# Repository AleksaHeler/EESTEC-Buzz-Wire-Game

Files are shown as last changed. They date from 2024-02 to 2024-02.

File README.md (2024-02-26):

# EESTEC-Buzz-Wire-Game

Buzz wire game HW for interactive booths made for EESTEC LC Novi Sad. Made in KiCAD and order from PCB manufaturer from China.

## Example

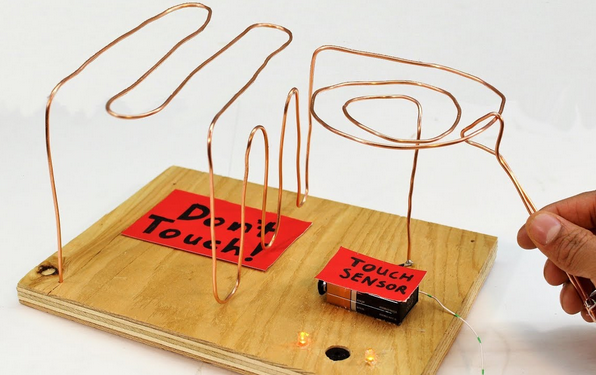
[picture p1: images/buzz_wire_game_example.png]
Buzz wire game example


## Idea

Idea is to make a simple custom HW board for visitors to play with and learn some basic electronics examples.

Using 555 timer chip create an oscillator which beeps a piezo buzzer when wires touch.

## Execution

TODO: add images:
 - schematic
 - PCB (KiCAD view, photos of actual PCBs)
 - board, mounting of all components

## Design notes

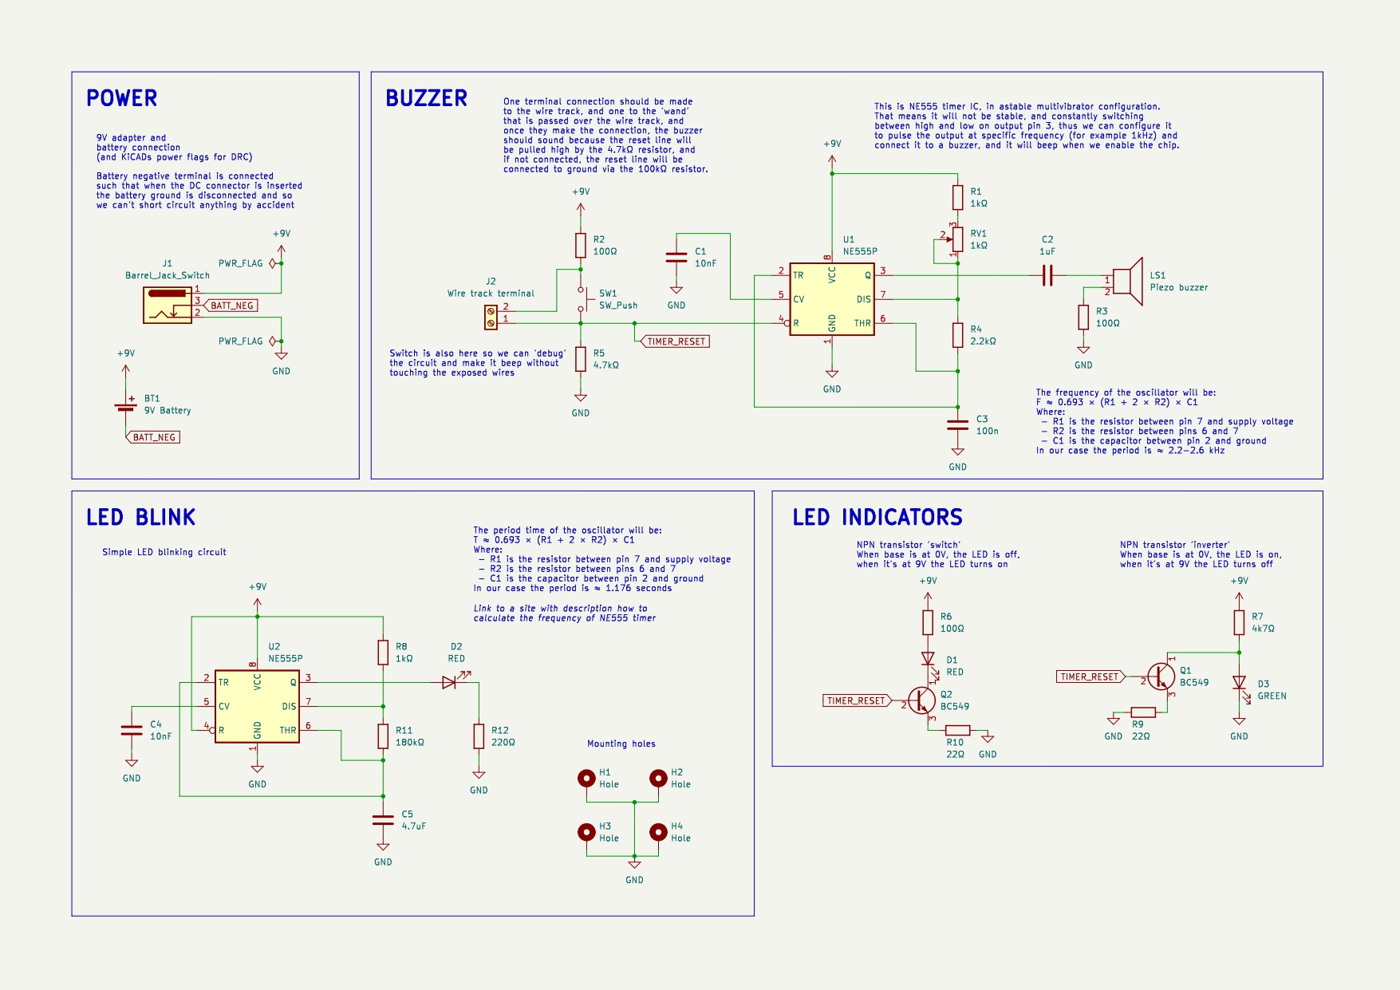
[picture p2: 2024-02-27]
images/Schematic.jpg

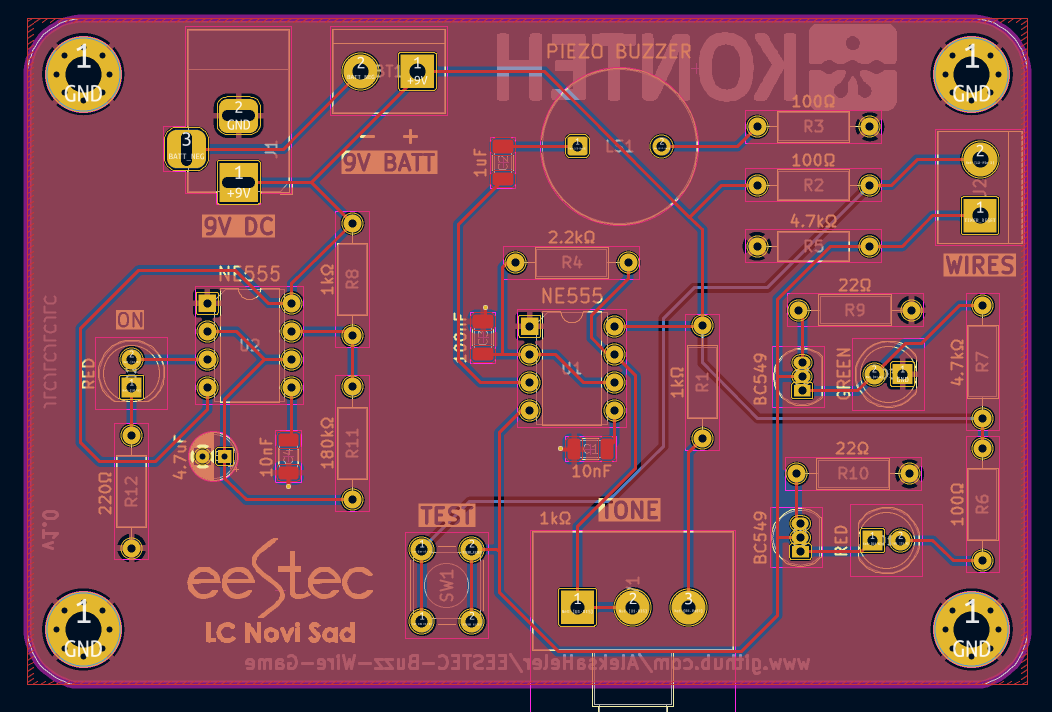
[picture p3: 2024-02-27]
images/PCB_KiCAD.png

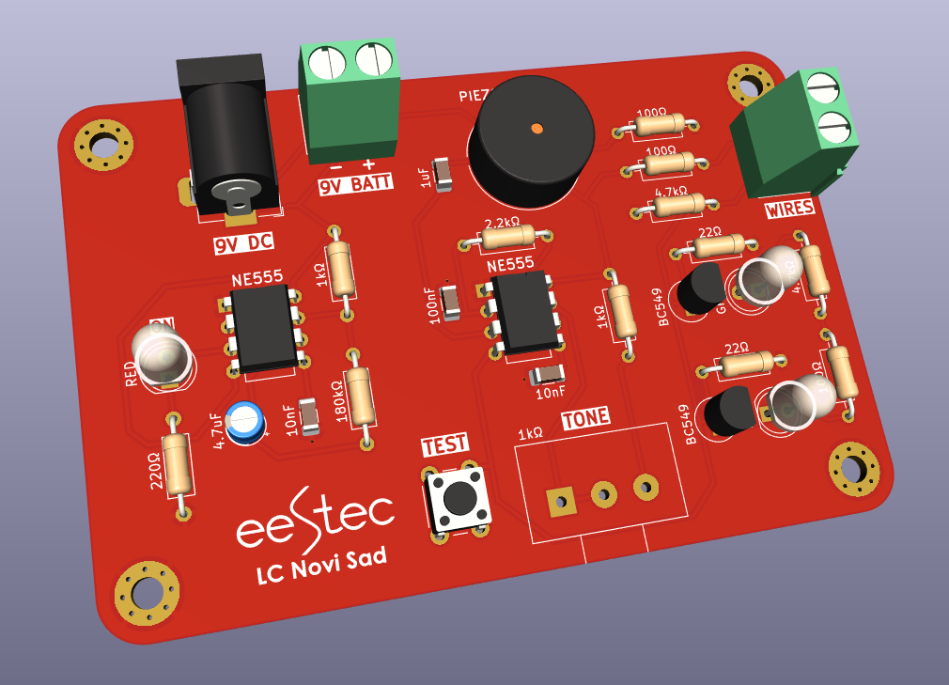
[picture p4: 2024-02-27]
images/PCB_3D_View.png

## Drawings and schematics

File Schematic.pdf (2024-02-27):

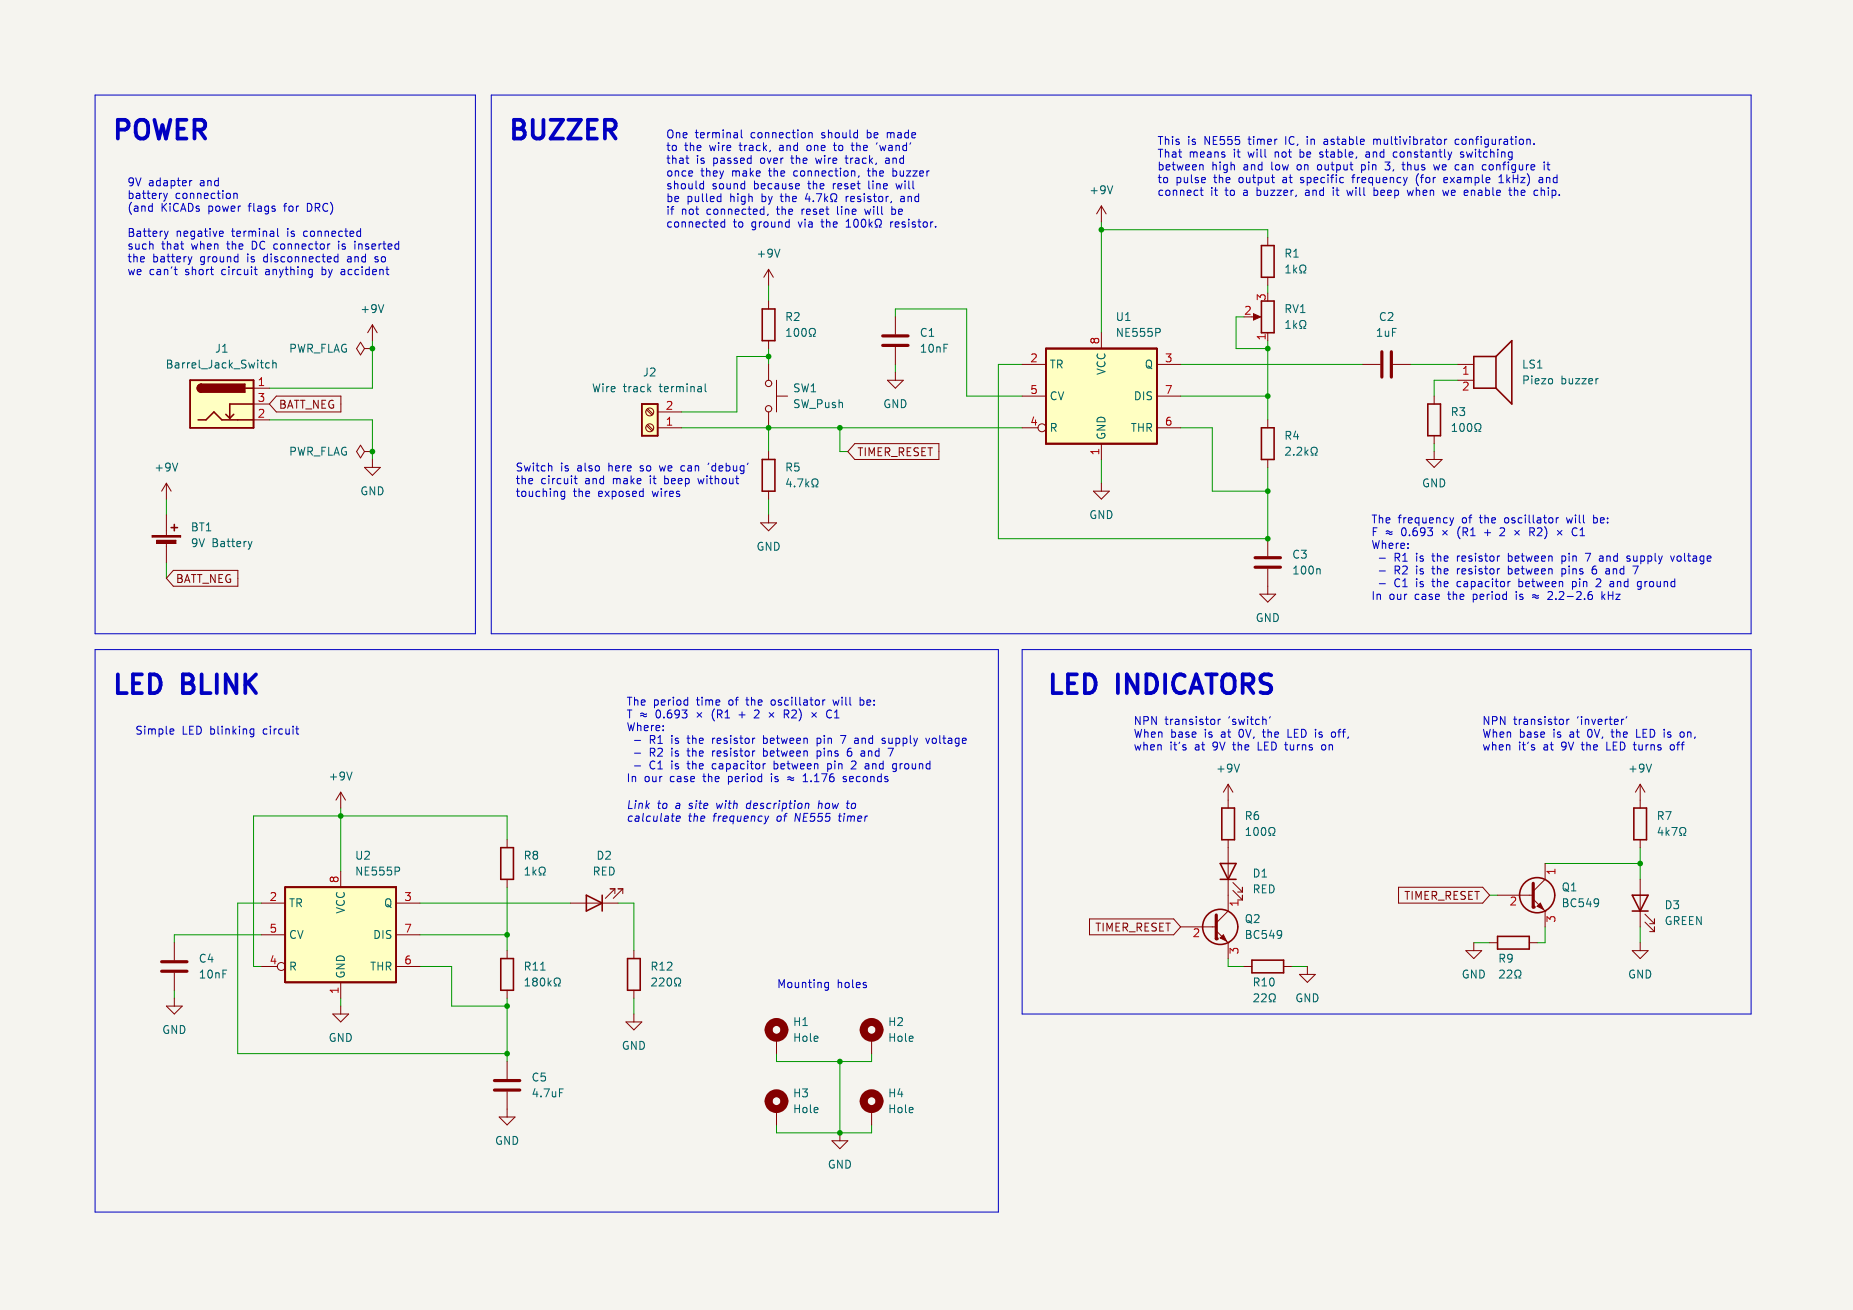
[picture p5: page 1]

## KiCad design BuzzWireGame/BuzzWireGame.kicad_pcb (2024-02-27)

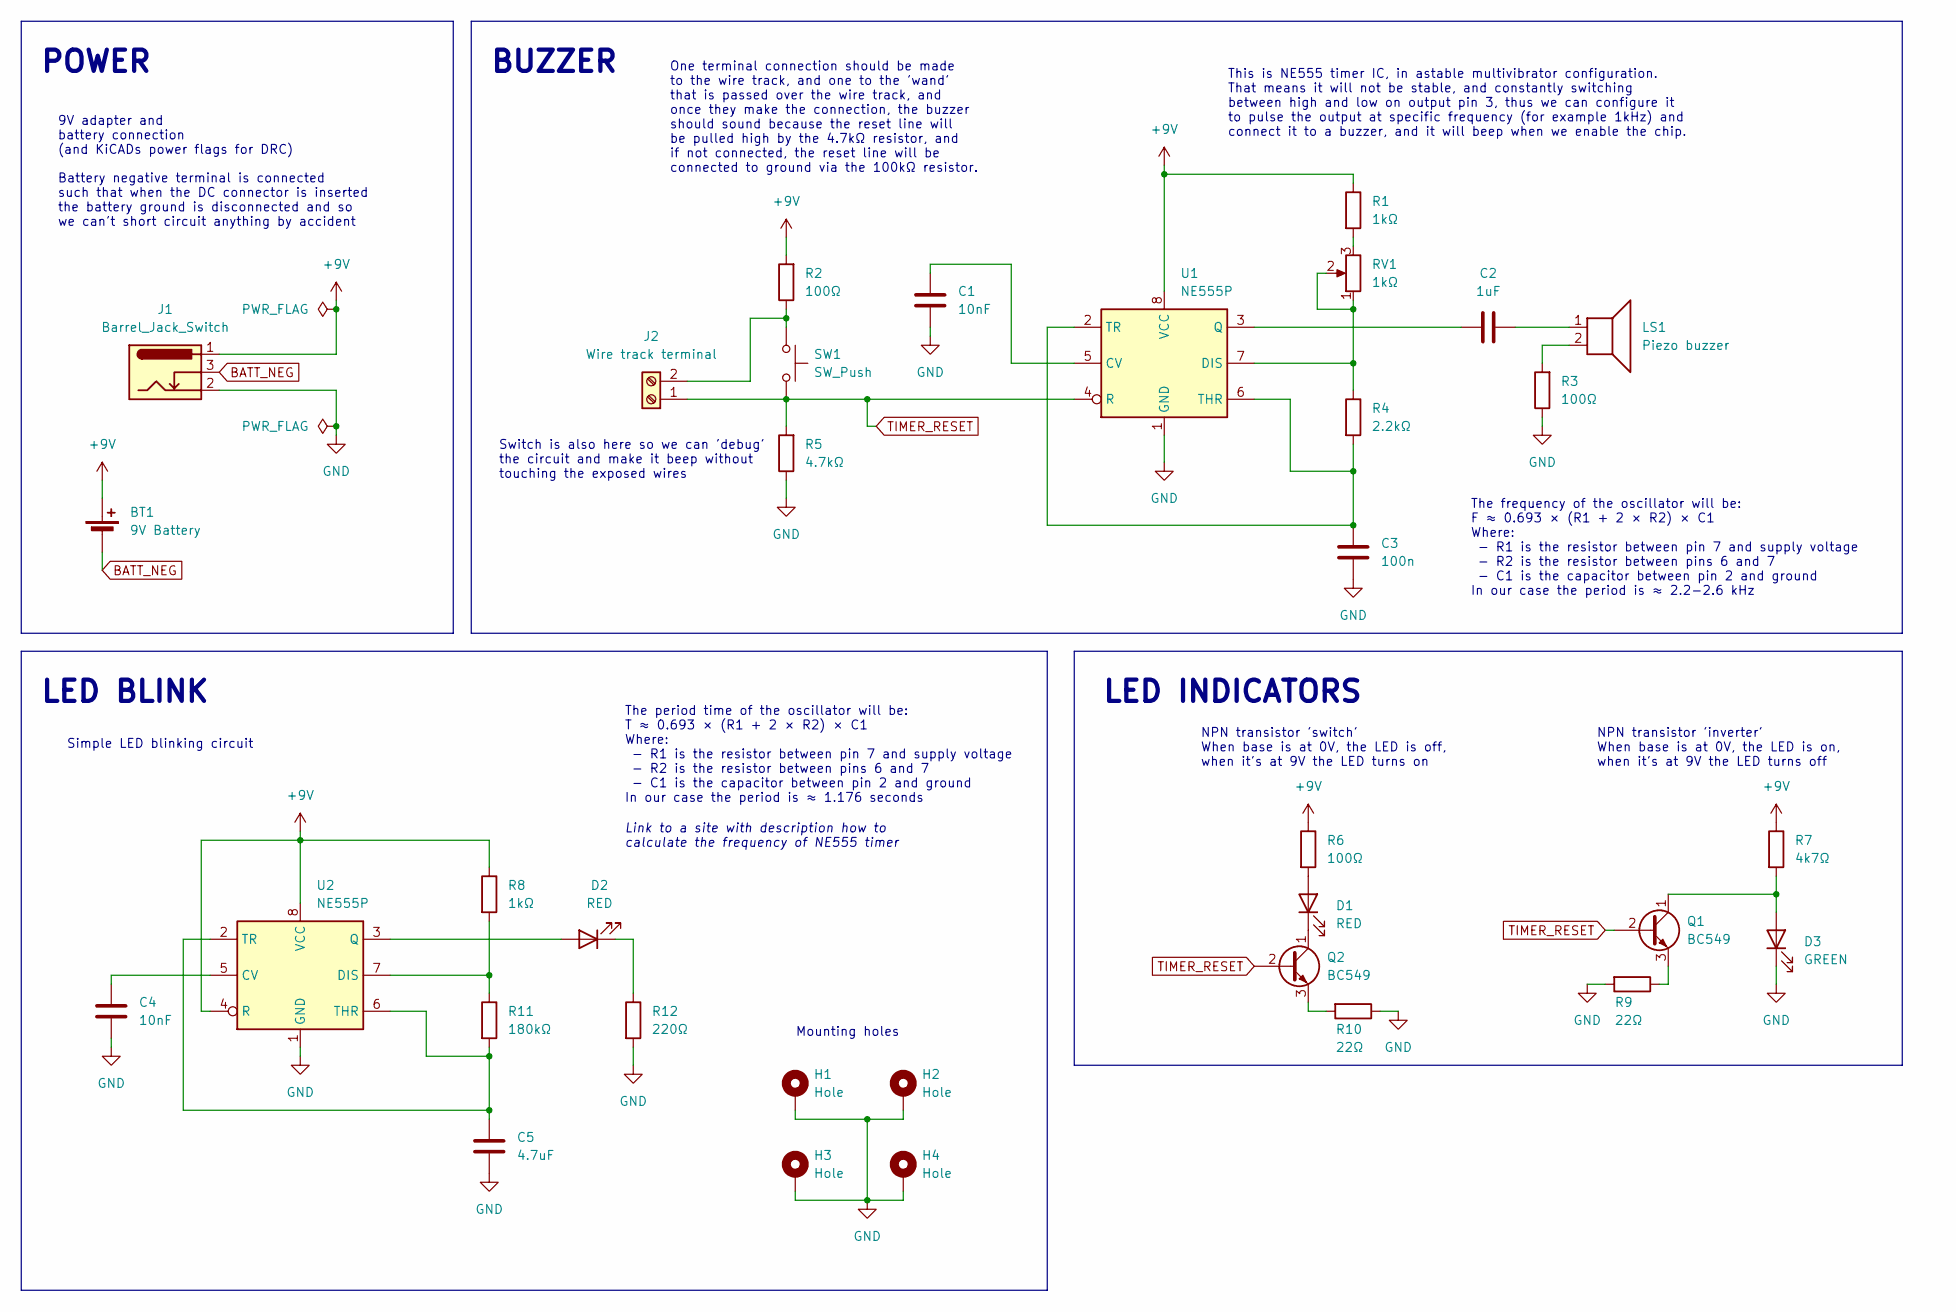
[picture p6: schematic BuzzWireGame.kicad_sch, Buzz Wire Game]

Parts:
BT1: 9V Battery; TerminalBlock_bornier-2_P5.08mm
C1, C4: 10nF; C_1206_3216Metric
C2: 1uF; C_1206_3216Metric
C3: 100n; C_1206_3216Metric
C5: 4.7uF; CP_Radial_D4.0mm_P2.00mm
D1, D2: RED; LED_D5.0mm_Clear
D3: GREEN; LED_D5.0mm_Clear
H1, H2, H3, H4: Hole; MountingHole_3.2mm_M3_Pad_Via
J1: Barrel_Jack_Switch; BarrelJack_Horizontal
J2: Wire track terminal; TerminalBlock_bornier-2_P5.08mm
LS1: Piezo buzzer; Indicator_PUI_AI-1440-TWT-24V-2-R
Q1, Q2: BC549; TO-92_Inline
R1, R8: 1kΩ; R_Axial_DIN0207_L6.3mm_D2.5mm_P10.16mm_Horizontal
R2, R3, R6: 100Ω; R_Axial_DIN0207_L6.3mm_D2.5mm_P10.16mm_Horizontal
R4: 2.2kΩ; R_Axial_DIN0207_L6.3mm_D2.5mm_P10.16mm_Horizontal
R5: 4.7kΩ; R_Axial_DIN0207_L6.3mm_D2.5mm_P10.16mm_Horizontal
R7: 4k7Ω; R_Axial_DIN0207_L6.3mm_D2.5mm_P10.16mm_Horizontal
R9, R10: 22Ω; R_Axial_DIN0207_L6.3mm_D2.5mm_P10.16mm_Horizontal
R11: 180kΩ; R_Axial_DIN0207_L6.3mm_D2.5mm_P10.16mm_Horizontal
R12: 220Ω; R_Axial_DIN0207_L6.3mm_D2.5mm_P10.16mm_Horizontal
RV1: 1kΩ; Potentiometer_Alps_RK163_Single_Horizontal
SW1: SW_Push; SW_PUSH_6mm_H4.3mm
U1, U2: NE555P; DIP-8_W7.62mm

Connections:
+9V: BT1.1 (+), J1.1, R1.1, R2.2, R6.1, R7.1, R8.1, U1.8 (VCC), U2.4 (R), U2.8 (VCC)
BATT_NEG: BT1.2 (-), J1.3
GND: C1.2, C3.2, C4.2, C5.2, D3.1 (K), H1.1, H2.1, H3.1, H4.1, J1.2, R3.1, R5.1, R9.2, R10.1, R12.2, U1.1 (GND), U2.1 (GND)
unnamed: C2.2, LS1.1
unnamed: D1.2 (A), R6.2
unnamed: D1.1 (K), Q2.1 (C)
unnamed: D2.2 (A), U2.3 (Q)
unnamed: D2.1 (K), R12.1
unnamed: D3.2 (A), Q1.1 (C), R7.2
unnamed: J2.2, R2.1, SW1.1
unnamed: LS1.2, R3.2
unnamed: Q1.3 (E), R9.1
unnamed: Q2.3 (E), R10.2
unnamed: R1.2, RV1.3
unnamed: C1.1, U1.5 (CV)
unnamed: R4.1, RV1.1, RV1.2, U1.7 (DIS)
unnamed: C2.1, U1.3 (Q)
unnamed: C3.1, R4.2, U1.2 (TR), U1.6 (THR)
unnamed: C4.1, U2.5 (CV)
unnamed: R8.2, R11.1, U2.7 (DIS)
unnamed: C5.1, R11.2, U2.2 (TR), U2.6 (THR)
TIMER_RESET: J2.1, Q1.2 (B), Q2.2 (B), R5.2, SW1.2, U1.4 (R)

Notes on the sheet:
LED BLINK
One terminal connection should be made to the wire track, and one to the 'wand' that is passed over the wire track, and once they make the connection, the buzzer should sound because the reset line will be pulled high by the 4.7kΩ resistor, and if not connected, the reset line will be connected to 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
Battery negative terminal is connected such that when the DC connector is inserted the battery ground is disconnected and so we can't short circuit anything by accident
POWER
9V adapter and battery connection (and KiCADs power flags for DRC)
Mounting holes
Simple LED blinking circuit
This is NE555 timer IC, in astable multivibrator configuration. That means it will not be stable, and constantly switching between high and low on output pin 3, thus we can configure it to pulse the output at specific frequency (for example 1kHz) and connect it to a buzzer, and it will beep when we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
NPN transistor 'inverter' When base is at 0V, the LED is on, when it's at 9V the LED turns off
LED INDICATORS
The frequency of the oscillator will be: F ≈ 0.693 × (R1 + 2 × R2) × C1 Where: - R1 is the resistor between pin 7 and supply voltage - R2 is the resistor between pins 6 and 7 - C1 is the capacitor between pin 2 and ground In our case the period is ≈ 2.2-2.6 kHz
BUZZER
NPN transistor 'switch' When base is at 0V, the LED is off, when it's at 9V the LED turns on
Switch is also here so we can 'debug' the circuit and make it beep without touching the exposed wires
Link to a site with description how to calculate the frequency of NE555 timer
The period time of the oscillator will be: T ≈ 0.693 × (R1 + 2 × R2) × C1 Where: - R1 is the resistor between pin 7 and supply voltage - R2 is the resistor between pins 6 and 7 - C1 is the capacitor between pin 2 and ground In our case the period is ≈ 1.176 seconds

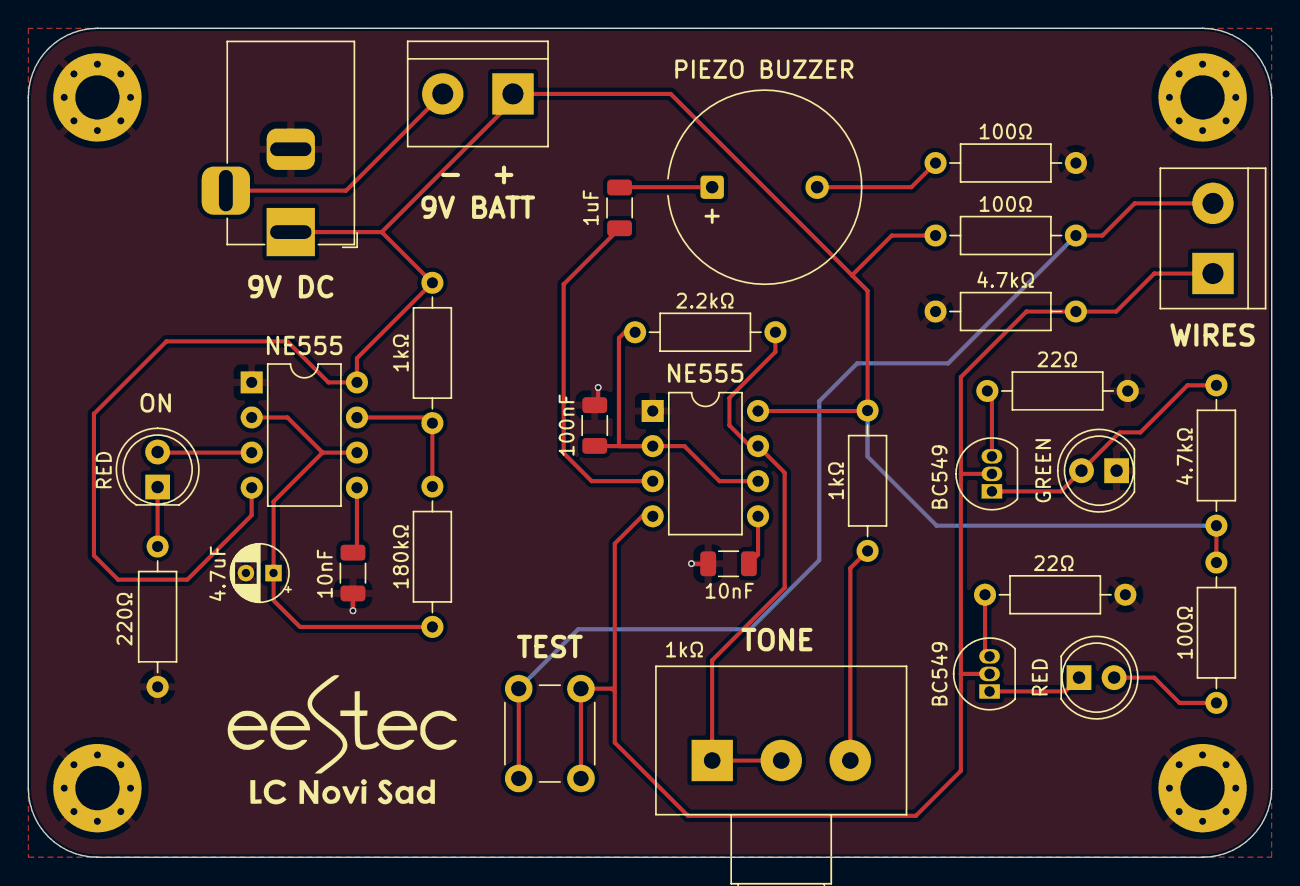
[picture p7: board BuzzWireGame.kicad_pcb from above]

Board: 2 copper layers, 90.0 x 60.0 mm, 34 parts (0 on the bottom side), 22 nets.

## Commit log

2024-02-26 Start with schematics
    [BuzzWireGame.kicad_pcb, BuzzWireGame.kicad_sch]
2024-02-27 Finish schm and PCB design for v1.0
    [BuzzWireGame-B_Cu.gbr, BuzzWireGame-B_Mask.gbr, BuzzWireGame-B_Paste.gbr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]
